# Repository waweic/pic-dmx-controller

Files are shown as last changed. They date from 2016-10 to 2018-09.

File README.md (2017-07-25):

# pic-dmx-controller
A friend of mine did in his Internship at the Institute for Automation some developing.
He used the CCS C-Compiler, so You will have to use the same.
In the main Folder, you will find a .hex and a .dll file. The .hex file should be flashed to a PIC18f4550, the .dll file is a plugin for PCDIMMER. The Electronics are not yet tested on a real DMX-Device, but they ARE tested on a Oscillsocope. 
The electronics should cost about 15€, but you don't have to use the most expensive parts, e.d the DC/DC Converter and the Octocoupler.
To use the Plugin, You first have to install the Driver, brought in the Driver Folder. 
It is until now just made for Windows and i would really like, if somebody could implement a linux driver.

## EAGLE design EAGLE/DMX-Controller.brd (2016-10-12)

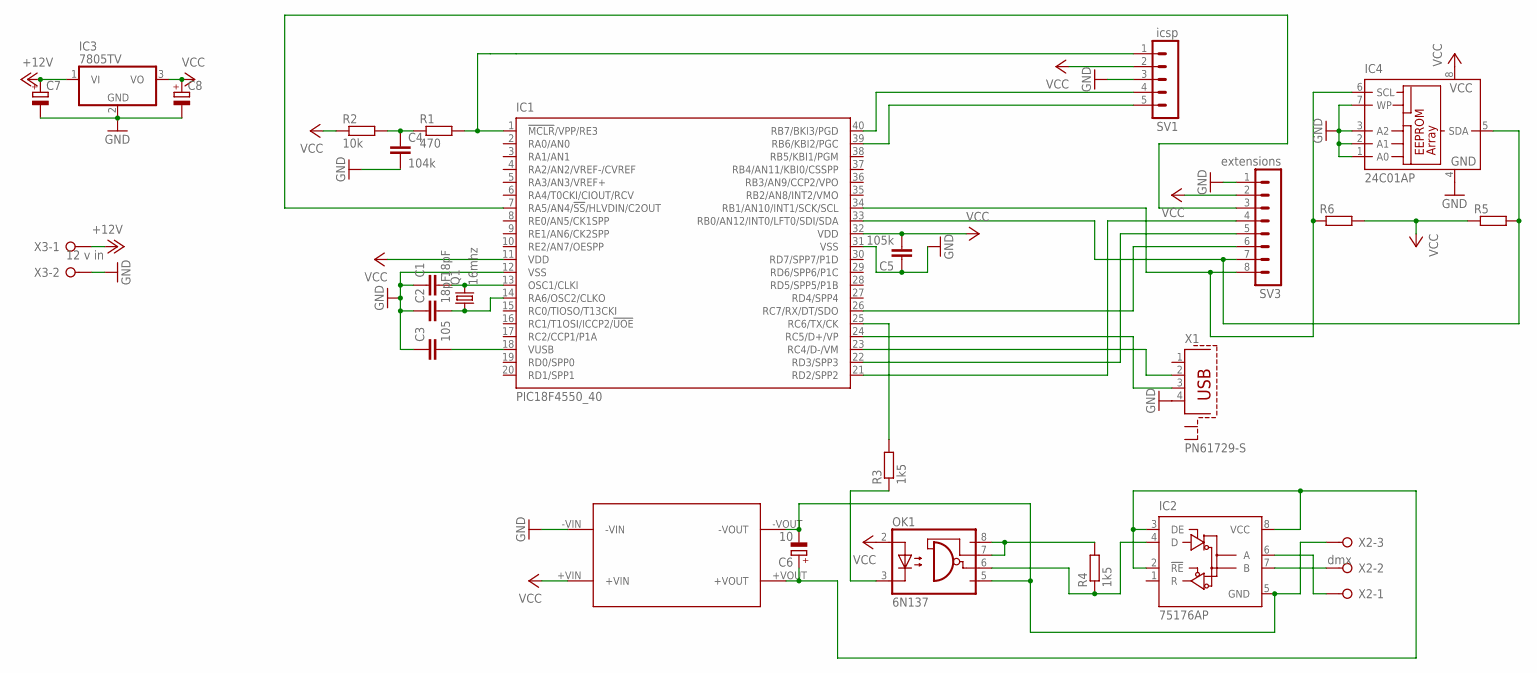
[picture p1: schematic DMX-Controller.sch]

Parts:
C1, C2: 18pF; C050-024X044
C3: 105; C050-024X044
C4: 104k; C050-024X044
C5: 105k; C050-024X044
C6: 10; E2,5-6
C7, C8: CPOL-EUE2.5-6; E2,5-6
IC1: PIC18F4550_40; DIL40
IC2: 75176AP; DIL08
IC3: 7805TV; TO220V
IC4: 24C01AP; DIL8
OK1: 6N137; DIL08
Q1: 16mhz; HC49U-V
R1: 470; 0207/10
R2: 10k; 0207/10
R3, R4: 1k5; 0207/10
R5, R6: R-EU_0207/10; 0207/10
SV1: icsp; MA05-1
SV3: extensions; MA08-1
U$1: SIM1-0505SZ; SIM-0505SZ
X1: PN61729-S
X2: dmx; W237-3E
X3: 12 v in; W237-132

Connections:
+12V: C7.+, IC3.1 (VI), X3.1
GND: C1.1, C2.1, C3.1, C4.2, C5.1, C7.-, C8.-, IC1.12 (VSS), IC1.31 (VSS), IC3.2 (GND), IC4.1 (A0), IC4.2 (A1), IC4.3 (A2), IC4.4 (GND), IC4.7 (WP), SV1.3, SV3.1, U$1.-VIN, X1.4, X3.2
unnamed: C1.2, IC1.13 (OSC1/CLKI), Q1.2
unnamed: C2.2, IC1.14 (RA6/OSC2/CLKO), Q1.1
unnamed: C3.2, IC1.18 (VUSB)
unnamed: IC1.1 (!MCLR!/VPP/RE3), R1.2, SV1.1
unnamed: IC1.7 (RA5/AN4/!SS!/HLVDIN/C2OUT), SV3.3
unnamed: IC1.40 (RB7/BKI3/PGD), SV1.4
unnamed: IC1.24 (RC5/D+/VP), X1.3
unnamed: IC1.23 (RC4/D-/VM), X1.2
unnamed: IC1.39 (RB6/KBI2/PGC), SV1.5
unnamed: OK1.3 (C), R3.1
unnamed: C6.-, IC2.5 (GND), OK1.5 (GND), U$1.-VOUT, X2.3
unnamed: C6.+, IC2.2 (!RE), IC2.3 (DE), IC2.8 (VCC), U$1.+VOUT
unnamed: IC1.25 (RC6/TX/CK), R3.2
unnamed: IC1.34 (RB1/AN10/INT1/SCK/SCL), IC4.6 (SCL), R6.1, SV3.8
unnamed: IC1.21 (RD2/SPP2), SV3.4
unnamed: OK1.7 (VE), OK1.8 (VCC), R4.2
unnamed: IC2.4 (D), OK1.6 (VO), R4.1
unnamed: IC1.22 (RD3/SPP3), SV3.5
unnamed: IC1.26 (RC7/RX/DT/SDO), SV3.6
unnamed: IC1.33 (RB0/AN12/INT0/LFT0/SDI/SDA), IC4.5 (SDA), R5.2, SV3.7
unnamed: IC2.6 (A), X2.1
unnamed: IC2.7 (B), X2.2
unnamed: C4.1, R1.1, R2.2
VCC: C5.2, C8.+, IC1.11 (VDD), IC1.32 (VDD), IC3.3 (VO), IC4.8 (VCC), OK1.2 (A), R2.1, R5.1, R6.2, SV1.2, SV3.2, U$1.+VIN

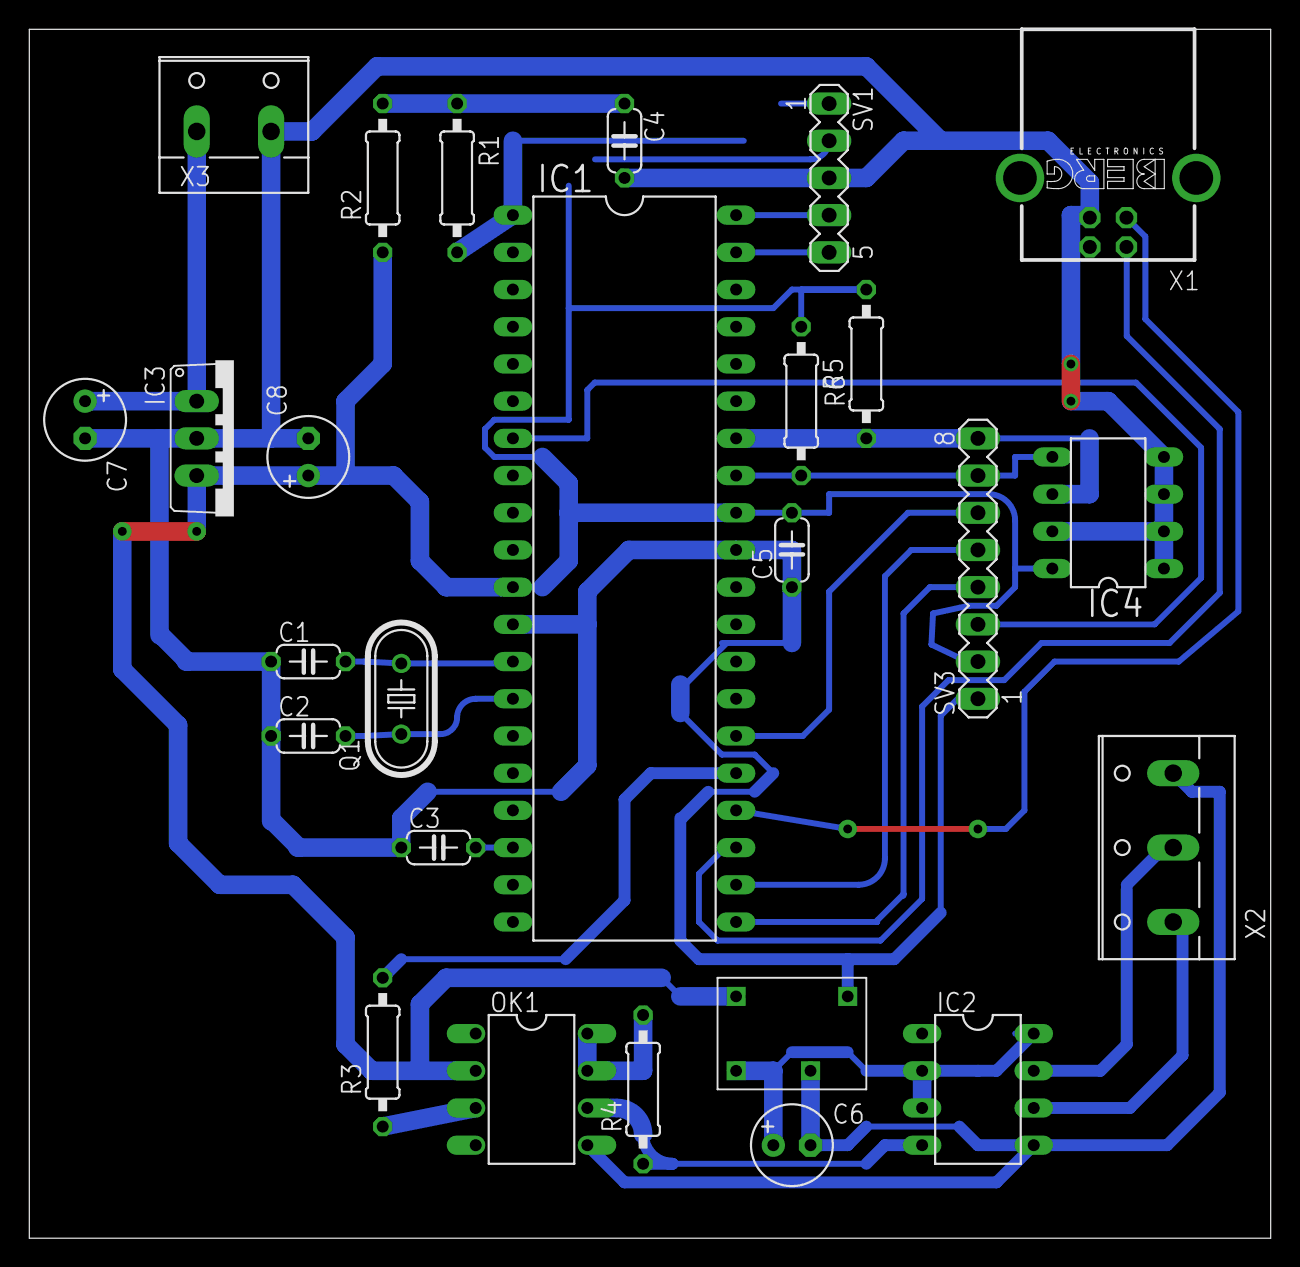
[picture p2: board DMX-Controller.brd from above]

Board: 2 copper layers, 84.8 x 82.5 mm, 26 parts (0 on the bottom side), 26 nets.

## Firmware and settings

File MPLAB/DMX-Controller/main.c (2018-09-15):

#include <18F4550.h>

#device *=16

#case

#fuses HS,NOWDT,NOPROTECT,NOLVP,NODEBUG,USBDIV,PLL4,CPUDIV1,VREGEN
#use delay(clock=16000000)


////////////////////DMX-TEIL//////////////////////////////////////////
#use rs232(baud=250000,parity=N,xmit=PIN_C6,rcv=PIN_C7, stop=2,stream=DMXX)
#use timer(timer=1,tick=10ms,bits=16,isr)
#define DMXANZA 255 //Die Menge der mit dem Gerät ansprechbaren Kanäle
#define DMXANZB 255 //Wird vermutlich nicht genutzt

////////////////////USB-TEIL//////////////////////////////////////////
#define MAX_USB_PACKET_SIZE 64
#define USB_FULL_SPEED     TRUE
#define USB_HID_DEVICE     FALSE            //disabled HID
#define USB_EP1_TX_ENABLE  USB_ENABLE_BULK  //turn on EP1(EndPoint1) for IN bulk/interrupt transfers
#define USB_EP1_RX_ENABLE  USB_ENABLE_BULK  //turn on EP1(EndPoint1) for OUT bulk/interrupt transfers
#define USB_EP1_TX_SIZE    64               //size to allocate for the tx endpoint 1 buffer
#define USB_EP1_RX_SIZE    64               //size to allocate for the rx endpoint 1 buffer

unsigned char  valuea[DMXANZA]; //Die Werte pro Kanal. Vermutlich entspricht valuea[0] dem Wert für Kanal 1
//unsigned char  valueb[DMXANZB];
unsigned int dmxnum;
unsigned int status;

// ?
#include <pic18_usb.h>
#include "usb_desc_controller.h"
#include <usb.c>
#include <stdlib.h>


void senddata(char* sendstring){ //Sende einen String an den Computer
    usb_puts (1, sendstring, strlen(sendstring), 40);
    //output_toggle(PIN_B0);
}

void getitall(char* test) { //Lies alle über USB empfangenen Daten in einen String
    unsigned int8 rxdata[64];
    unsigned int8 rxdata_len;    
    rxdata_len = usb_get_packet (1, rxdata, 64);
    rxdata[rxdata_len] = 0;
    /*for(int i = 0;i<sizeof(rxdata);i++){
        if(i >= rxdata_len){
            rxdata[i] = '\0';
        }    
    }*/
    strcpy(test, rxdata);
}  

void init_dmx(void)
{
   set_uart_speed(250000, DMXX); //Baudrate für Break bzw. Reset. Vermutlich hier unnötig, weil die später eh geändert wird
   //output_high(sn75176); //RS458-Wandler auf Sendemodus versetzen; high: transmit low: receive //später nachrüsten

   status=1; //mit Break bzw. Reset beginnen
}


#ifdef __PCM_
#bit SPEN = 0x18.7
#else
#bit SPEN = 0xFAB.7
#endif

#define UART_ON  SPEN=1
#define UART_OFF SPEN=0 

#byte TXSTA = 0xFAC
#bit TRMT = TXSTA.1

#include <stdlib.h> //Warum hier?

void main(void)
{  
    int dmxsize = 10;
    for(int i=0; i < DMXANZA; i++) {
	valuea[i] = 0; 
	}
    //for(int i=0; i<DMXANZB; i++) {
	//valueb[i] = 0; 
	//}
   delay_ms(500); //Dem Controller etwas Zeit geben, nur zur Sicherheit
   usb_init();
   usb_wait_for_enumeration();
   // Ab hier haben wir eine USB-Bulk-Verbindung zum Rechner
   init_dmx();
   //set_timer0(0);
   //setup_counters( RTCC_INTERNAL, RTCC_DIV_256 | RTCC_8_BIT);
   //enable_interrupts(INT_RTCC);
   //enable_interrupts(GLOBAL);
   char meintest[64]; //Ist hier der buffer für die über USB eingelesenen Werte
  
   
   while(TRUE)
   {        
      do { 
       
      switch(status)
     {
         case 1:                //RESET (0 senden) //Warum nicht bei 0 starten?
             //UART_OFF;
             //output_low(PIN_C6);
             //delay_us(100);
             //output_high(PIN_C6);
             //delay_us(10);
             //UART_ON;
             delay_ms(10); //Wir haben zwar schon eine USB-Verbindung, geben ihr aber noch etwas Zeit.
             set_uart_speed(80000); //Mit dieser Geschwindigkeit gibt es einen Break der für DMX einen neuen Durchlauf bedeutet.
             putc(0x00, DMXX); //Break senden
             while(!TRMT); //Warten bis der Break gesendet wurde.
             set_uart_speed(250000); //Jetzt die Geschwindigkeit zurück auf das normale Maß
             putc(0x00, DMXX); //Der "nullte" Kanal ist immer 0
             
             status = 2; //Ab jetzt sollen Werte gesendet werden
             dmxnum = 0; //Wir beginnen bei Kanal 1, also 0 in valuea
         break;
         
         case 2: //DMX-Daten senden                   
               
             putc(valuea[dmxnum],DMXX); // Sende den aktuellen DMX Wert
             dmxnum++;
             if (dmxnum == dmxsize)
             {
                 status = 1;
             }
         break;
     }
      } while(status != 1); //Bevor wir den zweiten Durchlauf starten, muss zuerst geschaut werden, ob neue Daten über USB angekommen sind.
      
      if(usb_enumerated()) //Sicherstellen, dass wir eine USB-Verbindung haben
      {
         if(usb_kbhit(1)) //Sicherstellen, dass in Endpoint 1 Daten vorhanden sind
         {      
             getitall(meintest); //Das hier ist potentiell nicht sinnvoll, weil nicht sichergestellt werden kann, dass auch wirklich genug Daten da sind.
             char *ptra;
             char *ptrb;
             char delimiter[] = ";";
             // initialisieren und ersten Abschnitt erstellen
             ptra = strtok(meintest, delimiter); //String aufteilen, erster Wert geht in *ptra
 	     ptrb = strtok(NULL, delimiter); //String erneut aufteilen, alles bzw. alles bis zum nächsten Semikolon geht in *ptrb
 	     if(atoi(ptra) - 1 > dmxsize ) {
 	         dmxsize = atoi(ptra); //Die Anzahl der zu sendenden Kanäle wird erhöht, weil ein neuer Kanal da ist
	     }
 	     valuea[atoi(ptra) - 1] = atoi(ptrb); //Der Krams nach dem Semikolon wird in ein int umgewandelt und in valuea eingespeichert. Die Größe wird hier gar nicht gestestet.
 	     senddata(meintest); //Sende den empfangenen Krams zurück über USB
         }
      }

     
      
   }
}

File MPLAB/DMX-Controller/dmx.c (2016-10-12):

/////////////////////////////////////////////////////////////////////////
////                            RS485.c                              ////
////                                                                 ////
////      This file contains drivers for RS-485 communication        ////
/////////////////////////////////////////////////////////////////////////
////                                                                 ////
//// int1 rs485_get_message(int* data_ptr, int wait)                 ////
////     * Get a message from the RS485 bus                          ////
////     * Address can be 1 - 33.                                    ////
////     * A 1 will be returned if a parity check error occurred.    ////
////                                                                 ////
//// int1 rs485_send_message(int to, int len, int* data)             ////
////     * Send a message over the RS485 bus                         ////
////     * Inputs:                                                   ////
////          to    - Destination address                            ////
////          len   - Message length                                 ////
////          *data - Pointer to message                             ////
////     * Returns TRUE if successful, FALSE if failed               ////
////                                                                 ////
//// void rs485_wait_for_bus(int1 clrwdt)                            ////
////     * Wait for the RS485 bus to open. Normally used before      ////
////       sending a message to avoid collisions.                    ////
////     * Pass in TRUE to restart the watch dog timer to prevent    ////
////       the device from resetting.                                ////
////     * This is not needed if sending an immediate response       ////
////                                                                 ////
/////////////////////////////////////////////////////////////////////////
////        (C) Copyright 1996, 2004 Custom Computer Services        ////
//// This source code may only be used by licensed users of the CCS  ////
//// C compiler.  This source code may only be distributed to other  ////
//// licensed users of the CCS C compiler.  No other use,            ////
//// reproduction or distribution is permitted without written       ////
//// permission.  Derivative programs created using this software    ////
//// in object code form are not restricted in any way.              ////
/////////////////////////////////////////////////////////////////////////
#include <18F4550.h>

#device *=16


#ifndef RS485_DRIVER
#define RS485_DRIVER

#ifndef RS485_ID
#define RS485_ID  0x10                 // The device's RS485 address or ID
#endif
#ifndef rs485_id
#define rs485_id  RS485_ID                 // The device's RS485 address or ID
#endif

#ifndef RS485_USE_EXT_INT
#define RS485_USE_EXT_INT FALSE        // Select between external interrupt
#endif                                 // or asynchronous serial interrupt


#if(RS485_USE_EXT_INT == FALSE)
   #ifndef RS485_RX_PIN
   #define RS485_RX_PIN       PIN_C7   // Data receive pin
   #endif

   #ifndef RS485_TX_PIN
   #define RS485_TX_PIN       PIN_C6   // Data transmit pin
   #endif

   #ifndef RS485_ENABLE_PIN
   #define RS485_ENABLE_PIN   PIN_B4   // Controls DE pin.  RX low, TX high.
   #endif

   #ifndef RS485_RX_ENABLE
   #define RS485_RX_ENABLE    PIN_B5   // Controls RE pin.  Should keep low.
   #endif

   #use rs232(baud=9600, xmit=RS485_TX_PIN, rcv=RS485_RX_PIN, enable=RS485_ENABLE_PIN, bits=9, long_data, errors, stream=RS485)
   #use rs232(baud=9600, xmit=RS485_TX_PIN, rcv=RS485_RX_PIN, enable=RS485_ENABLE_PIN, bits=9, long_data, force_sw, multi_master, errors, stream=RS485_CD)

   #if getenv("AUART")
      #define RCV_OFF() {setup_uart(FALSE);}
   #else
      #define RCV_OFF() {setup_uart(FALSE);}
   #endif
#else
   #ifndef RS485_RX_PIN
   #define RS485_RX_PIN       PIN_B0   // Data receive pin
   #endif

   #ifndef RS485_TX_PIN
   #define RS485_TX_PIN       PIN_B3   // Data transmit pin
   #endif

   #ifndef RS485_ENABLE_PIN
   #define RS485_ENABLE_PIN   PIN_B4   // Controls DE pin.  RX low, TX high.
   #endif

   #ifndef RS485_RX_ENABLE
   #define RS485_RX_ENABLE    PIN_B5   // Controls RE pin.  Should keep low.
   #define rs485_wait_time RS485_RX_ENABLE
   #endif

   #use rs232(baud=9600, xmit=RS485_TX_PIN, rcv=RS485_RX_PIN, enable=RS485_ENABLE_PIN, bits=9, long_data, errors, stream=RS485)
   #use rs232(baud=9600, xmit=RS485_TX_PIN, rcv=RS485_RX_PIN, enable=RS485_ENABLE_PIN, bits=9, long_data, multi_master, errors, stream=RS485_CD)

   #define RCV_OFF() {disable_interrupts(INT_EXT);}
#endif



#define RS485_wait_time 20             // Wait time in milliseconds

#bit    rs485_collision = rs232_errors.6

#ifndef RS485_RX_BUFFER_SIZE
#define RS485_RX_BUFFER_SIZE  40
#endif

unsigned int8 rs485_state, rs485_ni, rs485_no;
unsigned int8 rs485_buffer[RS485_RX_BUFFER_SIZE];


// Purpose:    Enable data reception
// Inputs:     None
// Outputs:    None
void RCV_ON(void) {
   #if (RS485_USE_EXT_INT==FALSE)
      while(kbhit(RS485)) {getc();} // Clear RX buffer. Clear RDA interrupt flag. Clear overrun error flag.
      #if getenv("AUART")
         setup_uart(UART_ADDRESS);
         setup_uart(TRUE);
      #else
         setup_uart(TRUE);
      #endif
   #else
      clear_interrupt(INT_EXT);
      enable_interrupts(INT_EXT);
   #endif
}


// Purpose:    Initialize RS485 communication. Call this before
//             using any other RS485 functions.
// Inputs:     None
// Outputs:    None
void rs485_init() {
   RCV_ON();
   rs485_state=0;
   rs485_ni=0;
   rs485_no=0;
   #if RS485_USE_EXT_INT==FALSE
   enable_interrupts(INT_RDA);
   #else
   ext_int_edge(H_TO_L);
   enable_interrupts(INT_EXT);
   #endif
   enable_interrupts(GLOBAL);
   output_low(RS485_RX_ENABLE);
}


// The index for the temporary receive buffer
unsigned int8 temp_ni;

// Purpose:    Add a byte of data to the temporary receive buffer
// Inputs:     The byte of data
// Outputs:    None
void rs485_add_to_temp(unsigned int8 b) {
   // Store the byte
   rs485_buffer[temp_ni] = b;

   // Make the index cyclic
   if(++temp_ni >= RS485_RX_BUFFER_SIZE)
   {
      temp_ni = 0;
   }
}
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
